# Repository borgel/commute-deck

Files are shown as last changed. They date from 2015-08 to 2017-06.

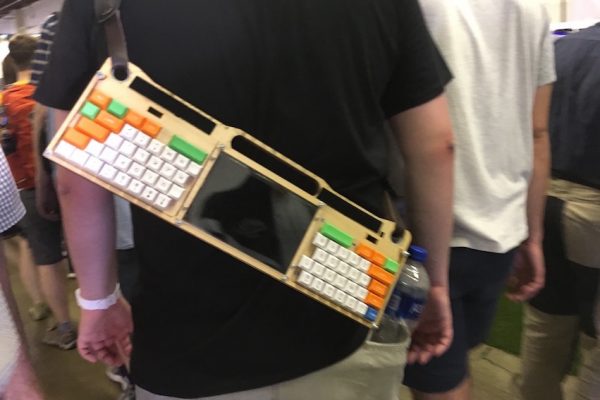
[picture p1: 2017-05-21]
media/commDeck_IMG_2097-600x400.jpeg

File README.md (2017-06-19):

# What?
A mechanical keyboard, Raspberry-Pi, battery and display all in one 24" wide box. A computer you can wear! Think of it as a [deck](https://www.google.com/search?q=neuromancer+deck) (a somewhat poorly defined computing device built from 90's hacker nostalgia) from William Gibson's [Sprawl Trilogy](https://en.wikipedia.org/wiki/Sprawl_trilogy).

It was built to make it comfortable to work in a UNIX terminal on the train. Though it turns out that staring straight down at the display isn't great long term.

[Adafruit found it](https://blog.adafruit.com/2017/05/21/maker-faire-bay-area-2017-commute-deck-rpi-workstation-makerfaire-raspberrypi/) at Maker Fair(e)!
Then [Make published my blog about it](http://makezine.com/2017/06/15/commute-deck-keyboard-device/)(with more description of the process of building it), and [BoingBoing found it too!](http://boingboing.net/2017/06/16/cyberspace-is-everting.html).

# What's it Made Of?
The big pieces are
* Laser cut plywood (there's a list of how many of each with the [mechanicals](/mechanicals)).
* A Raspberry-Pi (a Pi 2 in v1, but anything with HDMI should work).
* A 7" 720p screen
* A Teensy 2 running a modified version of the [tmk keyboard firmware](https://github.com/tmk/tmk_keyboard) and connected to the key matrix. It emulates a keyboard and mouse to the Pi.
* A 10,000 mAh LiPo battery (ripped apart and rearranged).
* Two USB hubs (one inside, one outside). WiFi and Bluetooth dongles attached inside.

## How To Build One
Ping me. Twitter is easiest (use my GitHub username) and we can start an email thread.

That out of the way... the high level is:
1. Laser cut the chassis using the DXFs in [mechanicals](/mechanicals).
2. Put the switches in the plywood.
3. As this isn't made by ripping apart an existing keyboard, they keyboard bit needs to be manufactured. And because we don't have any circuit boards everything needs to be connected by wires. In this case, that means soldering 2 connections to each of the ~60 switches (and more). Bite the bullet and hand wire the key matrix. This part sucks. There are [many](https://deskthority.net/workshop-f7/brownfox-step-by-step-t6050.html) excellent [guides](https://github.com/technomancy/atreus/wiki/BuildLogs) on assembling keyboards by hand. When I built this one, I copied from those and debugged until it worked.
4. Flash the keyboard's firmware. You'll want the `tmk_keyboard/keyboard/trainboard1.5/` directory inside the [firmware](/firmware) submodule. Follow or find instructions on building and flashing `tmk` to use it (the firmware itself includes a guide, so maybe start there).
5. Pull apart the battery if needed, and relocate it's charging/regulaton hardware/LEDs somewhere they are accessible from outside.
6. Bolt the battery, Pi, etc onto the bottom plate.
7. There is a top plate (which holds the switches), and a layer above that which mostly protects the edges of the keys. I glued mine together, which I think made it a bit more durable. If you'd like, you can glue together the three layers which include the handle. If you chose to glue things together, make sure to thread the bolts through to hold things in place!
8. Bolt the display between the front acrylic and the plate assembly from 6.
9. Connect the now large number of wires.
10. Slot everything together and tighten the bolts to hold it together!

# Parts
## The Chassis
* Plywood, acrylic, or similar. Something which can be laser cut. If you choose plywood, it should be extremely cheap. Personally I prefer the lighter weight and look of (ply)wood.
* A small section of acrylic (I chose something marketed as abrasion resistant) to cover and hold in the display.
* A display. Mine was 7" and 720p (https://www.amazon.com/gp/product/B00JOY5PGM/). You will need both the display AND a control board. I'd get both together to make sure they work together.
* A Raspberry-Pi (version doesn't matter as long as it can connect to the display)
* A battery. Again, pretty much anything works, but here's the one I used [https://www.amazon.com/gp/product/B00ITILPZ4]. At the time I chose it because it was thinish.
* A 12" HDMI cable to connect the Pi and display. If you move the Pi, changing the length might not hurt. I got my cable from [Monoprice](https://www.monoprice.com/).
* Fasteners. Uhhh, need to find a list of these
* If you want to wear it, I used two of these ["Guitar Strap Buttons"](https://www.amazon.com/gp/product/B00ZB6LMTG) to attach mine to [the cheapest guitar strap I could find](https://www.amazon.com/dp/B0002D0E92).
## The Keyboard
* Key switches for a mechanical keyboard is a whole _thing_. Here's a [disturbingly thurough guide](https://input.club/the-comparative-guide-to-mechanical-switches/). There are many places to get them, but I got mine from [mechanicalkeyboards.com](https://mechanicalkeyboards.com/shop/index.php?l=product_list&c=107).
* Key caps for the switches. Again, many places to get them, but [mechanicalkeyboards.com](https://mechanicalkeyboards.com/shop/index.php?l=product_list&c=40) works well.
* A Teensy 2.0 (https://www.pjrc.com/store/teensy.html). Other micros will work too, but if you're planning to use the `tmk` firmware it needs to be at ATMEGA of some sort. The Teensy 2.0 is a populat choice. Note: Newer Teensy's are much more powerful, but don't have ATMEGAs!
* Wire for the matrix
* Diodes for the matrix. I used 1N4148's but nearly anything will work (there aren't really any current or voltage constraints here). The specific ones I used are (https://www.amazon.com/gp/product/B00UXPVLEG)

# Other Info
http://www.keyboard-layout-editor.com/ is a great tool for prototyping keyboard layouts. If you have an idea you want to explore, I recommend playing with it. Unfortunately I'm not sure I generated a layout for this one (I can't find it at least).

Once you've created a layout with Keyboard Layout Editor you can pour it into http://builder.swillkb.com/, which can then generate files which can be laser cut or sent out for fabrication.

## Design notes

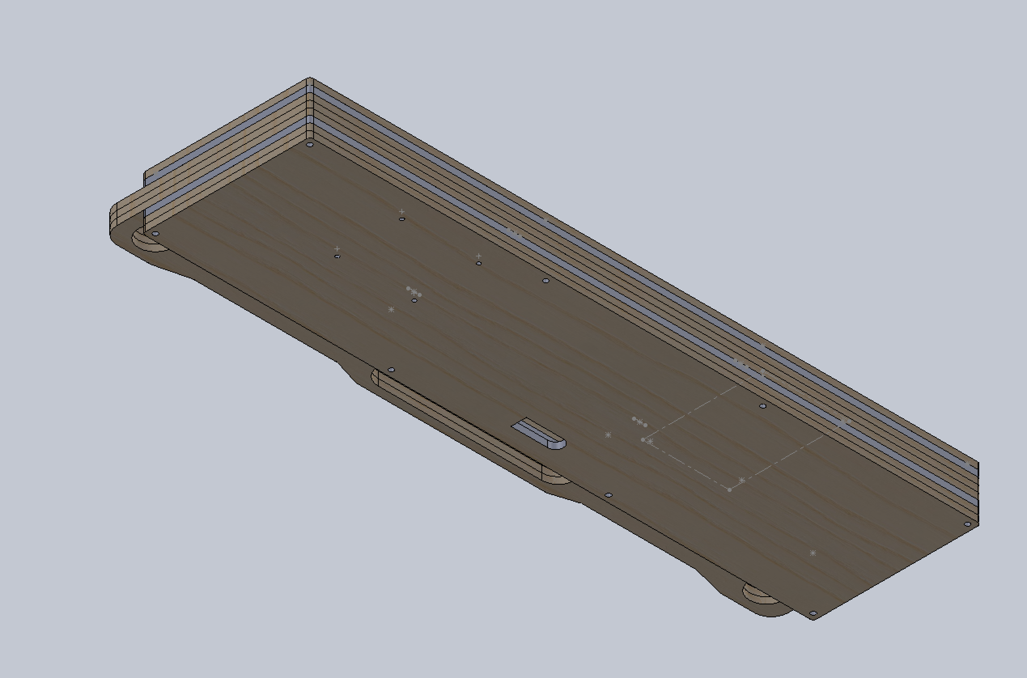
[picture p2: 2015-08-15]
media/Screenshot 2015-06-03 18.44.00.png

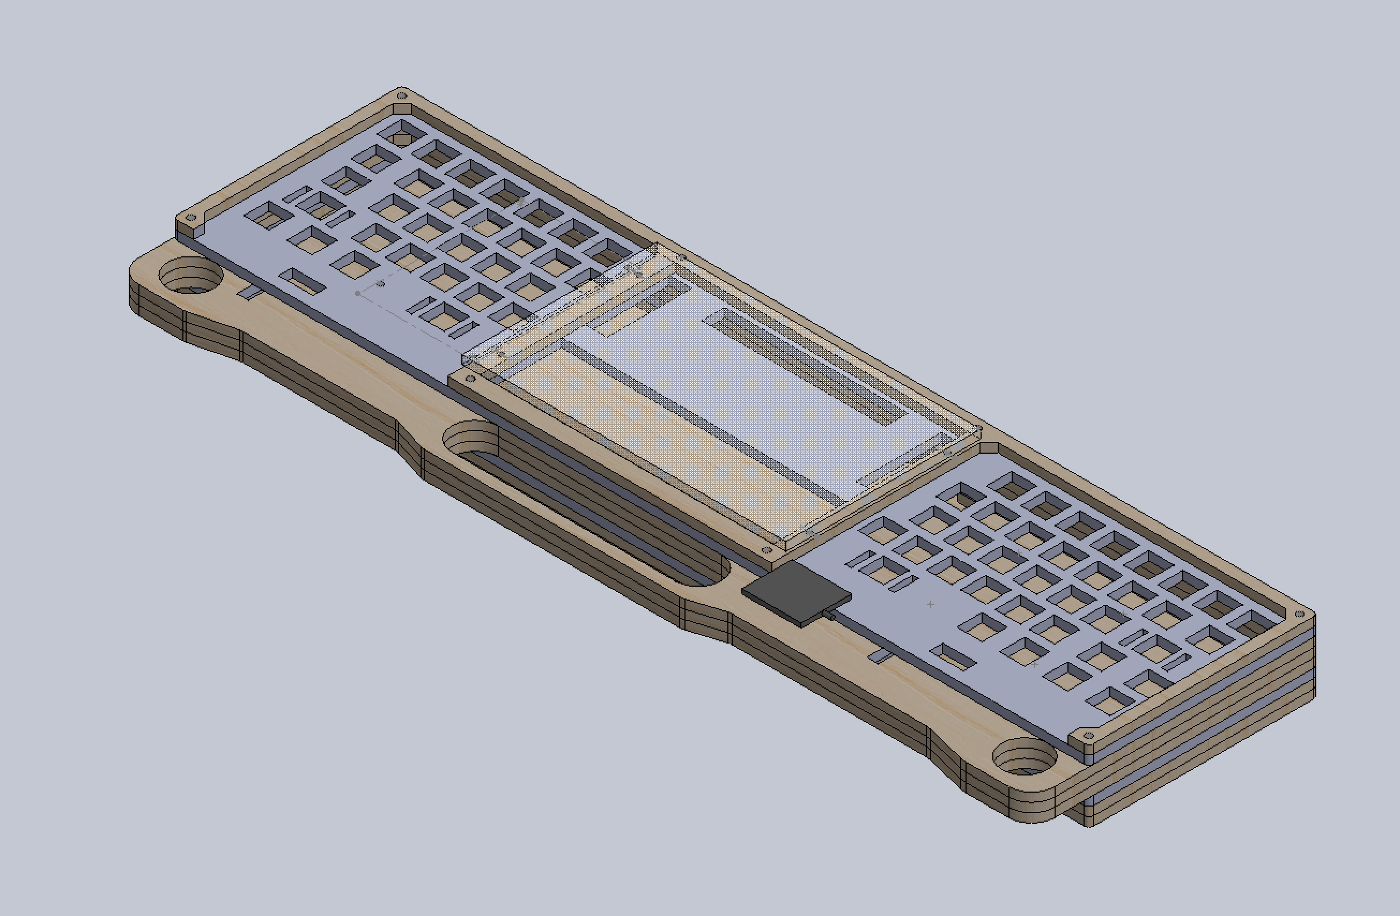
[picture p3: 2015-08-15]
media/Screenshot 2015-06-03 18.43.39.png

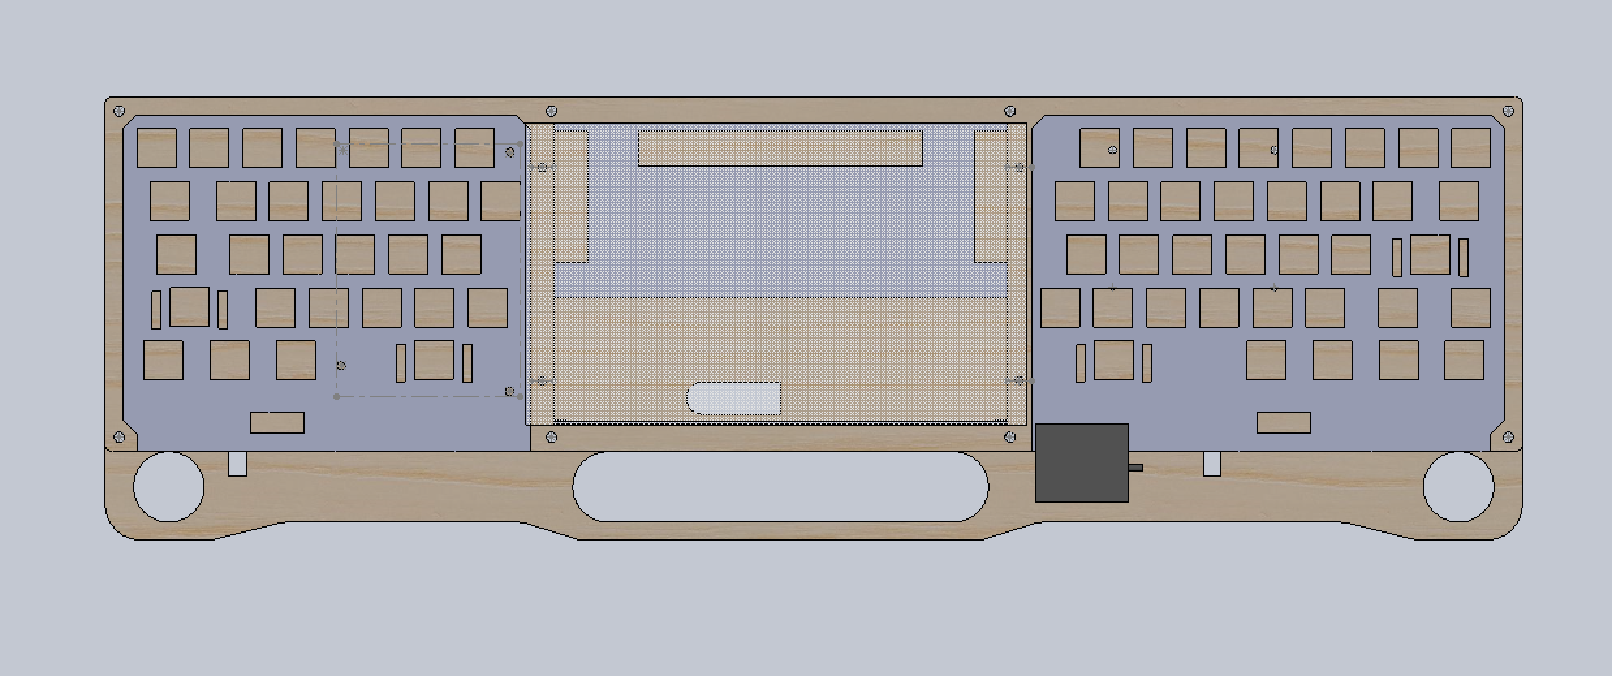
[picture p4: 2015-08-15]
media/Screenshot 2015-06-03 18.43.51.png

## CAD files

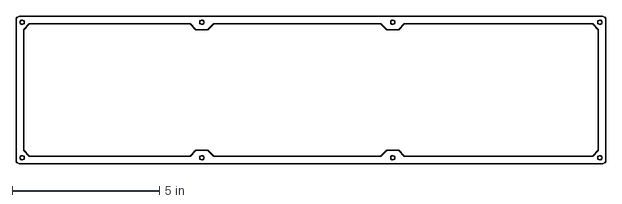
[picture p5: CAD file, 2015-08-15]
mechanicals/Spacer.DXF
20.0 x 5.00 in

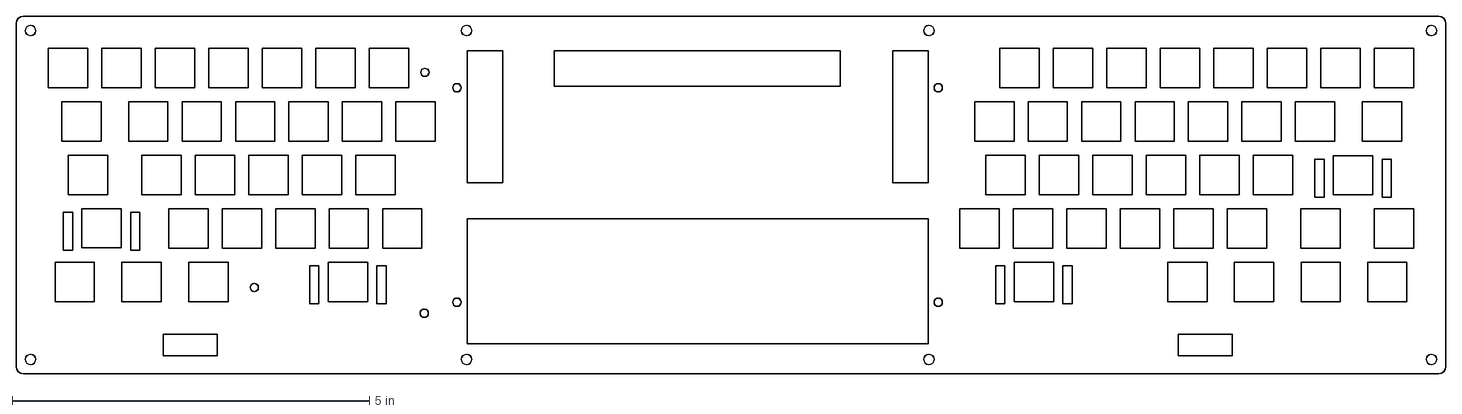
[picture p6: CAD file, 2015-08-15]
mechanicals/Top Deck.DXF
20.0 x 5.00 in

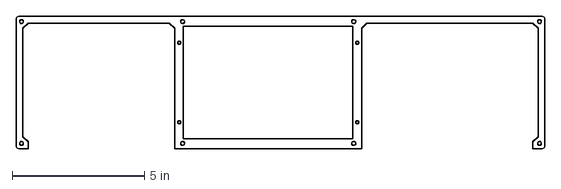
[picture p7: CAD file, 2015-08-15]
mechanicals/Top Fascia - Gaps.DXF
20.0 x 5.00 in

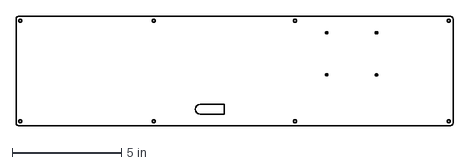
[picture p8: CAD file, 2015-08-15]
mechanicals/Back Plate.DXF
20.0 x 5.00 in

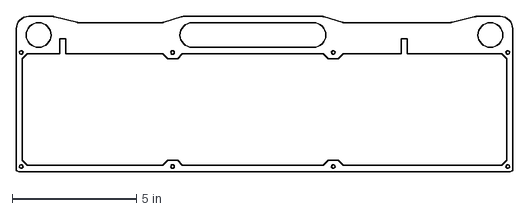
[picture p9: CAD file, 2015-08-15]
mechanicals/Spacer-Handle-Eyelits-WristRest.DXF
20.0 x 6.25 in

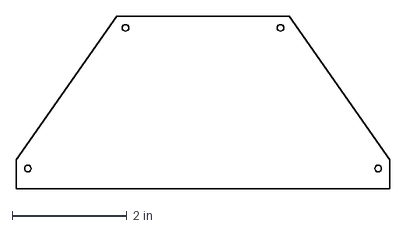
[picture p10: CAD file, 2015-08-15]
mechanicals/Battery Support Trapezoid.DXF
6.50 x 3.00 in

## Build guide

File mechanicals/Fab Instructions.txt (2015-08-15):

To Cut…

1 x Back Plate
1 x Top Deck
1 x Top Fascia - Gaps
2 x Spacer
3 x Spacer-Handle-Eyelist-WristRest
1 x Battery Support Trapezoid (can place DXF inside a larger part to save space)

Based on last time, that should fill most of the plywood. If there is any extra space, can you toss in more Spacers?

The plywood should have a label on it with thickness info. I /think it is .196” thick?

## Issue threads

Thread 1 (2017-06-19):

use a pair of modified belaying glasses for more comfort!

0xj9, 2017-06-19:
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

if you were to invert the prism (you might need another lens to correct the focal distance) you'd be able to look straight ahead and see your deck's screen without straining you neck.

borgel, 2017-06-22:
Wow, someone showed me these in a totally unrelated context this weekend! They would totally work.

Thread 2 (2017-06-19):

Alternate keyboard layouts

anEXPer, 2017-06-19:
I would very much like to build something like this.

My current travel keyboard is an open-source hardware project, the Atreus:
https://atreus.technomancy.us/

A big advantage of the atreus layout is that it's already a split, minimal format. I find the angled, ortholinear arrangement to be very comfortable for in-lap use, and other cramped circumstances.

It seems to me that it wouldn't be terribly difficult to combine big parts of both of these projects, though I'll have to look at it a little more closely to determine if I'd want to go about trying to do it.

Would you be interested in work to integrate the atreus keyboard layout?

borgel, 2017-06-22:
Awesome! I've been wanting to build an Atreus for a while :) I agree that the layout would be a great fit for something like this (you could reduce the width too, which wouldn't hurt). Plus more comfortable due to the angle. Are you thinking the classic? or the 62 key layout [1]?

Anyway, sure I'd be interested! The problem will be...how exactly to integrate them. The most obvious way is to edit or regenerate the DXF of the top plate that actually holds the switches, then when someone goes to fabricate it they can choose which to make. Though that doesn't allow for larger changes to the chassis (like overall width). What do you think?

[1] https://github.com/profet23/atreus62
